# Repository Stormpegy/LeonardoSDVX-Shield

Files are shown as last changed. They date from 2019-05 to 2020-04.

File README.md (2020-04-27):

# LeonardoSDVX-Shield

Open source IO shield for homebuilt SDVX / K-Shoot Mania style controllers.

Uses the kicad libraries by sparkfun 
https://github.com/sparkfun/SparkFun-KiCad-Libraries

Uses arduino-kicad-library by Alarm-Siren
https://github.com/Alarm-Siren/arduino-kicad-library

Originally built to use the cons&stuff leovxhq code but pinout has been modified to make some of the routing neater.

Cons&Stuff SDVX guide
[Cons&Stuff](https://consandstuff.github.io/rhythmcons/sound-voltex/sdvx-normal/)

Original code can be found here
[Cons & Stuff leovx Code](https://github.com/consandstuff/sdvx-diy/tree/master/code%20Leonardo/Arduino%20Leonardo)

LED Pinout code changes between original leovx/leovxhq and what is required for this board.  
To update this code look for line 18 on leovx or line 27 on leovxhq and replace with the new example.

Original
`uint8_t ledPins[] = {6,7,8,9,10,11,12};`

New
`uint8_t ledPins[] = {12,11,10,9,8,7,6};`

I won't tell you how to open and flash this code, just download the arduino IDE and google the rest, It's not too complicated, ask on discord if you need a hand.

## Changelog
REV 2 released

- Replaced JST-XH connector footprints with generic 2.54mm header footprints, original footprints were well out of spec and didn't fit 2.54mm headers/plugs; thank you SirusDoma (C&S discord) for bringing this to my attention.

- System pin rotated to have GND on the same side as all other connections (I have also forgotten why the system pin exists but I'm leaving it there /shrug)

- Removed white border on leonardo shield footprint, library updated and included.

## Pinout

|Button	| Pin # | Button # | LED Pin # |
|---|---|---|---|
|Start	| 13 | Button 1 | 12 |
|BT-A	| A0 | Button 2 | 11 |
|FX-L	| A1 | Button 3 | 10 |
|BT-B	| A2 | Button 4 | 9 |
|BT-C	| A3 | Button 5 | 8 |
|FX-R	| A4 | Button 6 | 7 |
|BT-D	| A5 | Button 7 | 6 |

Encoders | DATA 1 | DATA 2 |
|--------|--------|--------|
|Left knob  (VOL-L) | 0 | 1 |
|Right knob (VOL-R) | 2 | 3 |

## Images

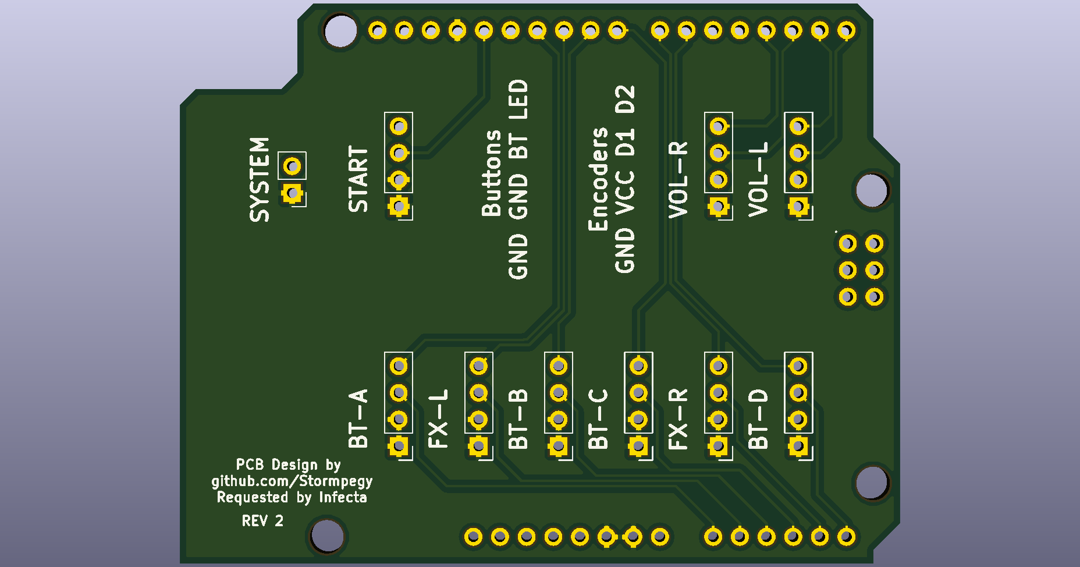
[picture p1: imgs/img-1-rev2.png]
Img Front


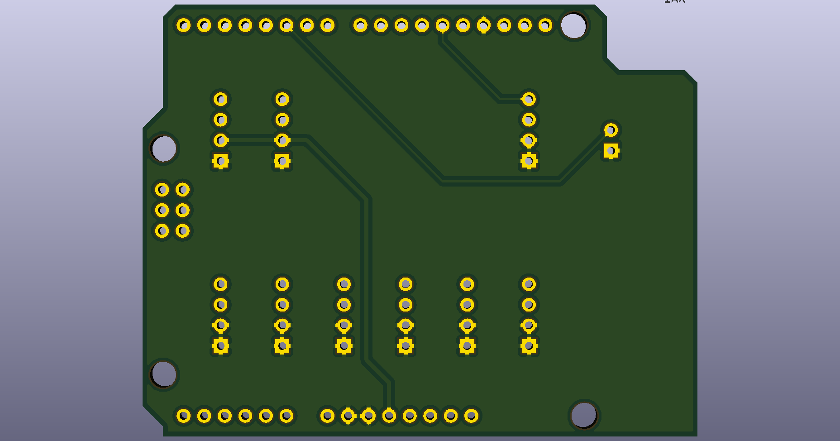
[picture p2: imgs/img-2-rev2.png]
Img Back


## Parts and construction

x32 header pins, standard 2.54mm spacing (Optional +2 if you wish to put headers on the system pins)

Very cheap, Can be found for as cheap as $1USD for 10pcs 40pin online.

x9 JST-XH 4 Pin style straight THT connectors (Ensure you get straight through hole, you will ~~likely~~ definitely struggle if you get right angle or smd)

These XH connectors can be found as sets with cables as well, It's recommend to get 25-35cm wires if you get a set.
JST brand is not important, Just ensure they are XH style spacing (2.5mm/2.54mm)

Crimps, Buttons, Leonardo and all the other parts to build a controller are also required but this just covers the parts for this shield, reference the cons&stuff for a great guide on making your own controller.

## Ordering
These can be ordered very cheaply through a PCB manufacturer such as JLCPCB, they cost $2USD for 5-10qty and shipping is around $5USD to Malaysia and $6USD to Australia.

Simply download LeonardoSDVX-Shield-Gerber.zip and upload it to your preferred PCB manufacturer, I use JLCPCB though there are plenty out there.

I highly recommend leaving the settings on JLCPCB as default unless you know what you're doing.

Layers - 2

Dimensions - 53 x 69 mm, don't change, it automatically enters these.

PCB thickness - 1.6mm

PCB Colour - Feel free to change this one though it will cost more, they use black silkscreen for white pcbs and white silkscreen for everything else.

Surface - HASL (with lead) (Other options are more expensive and not worth it for this simple board)

Copper weight - 1oz

Gold fingers - No

Panel - No

Different design - 1

## To do list
- [x] Make parts list

- [x] Add imgs to readme.md (this doc)

- [x] Add more info on the code change / LED pinout change

- [x] Modify the shield footprint to remove the white outline? unsure how that will go with manufacturing

- [x] Fix the big mistake on rev 1 :)

## Contact and Modifications
Created by https://github.com/Stormpegy
Feel free to contact me in the cons&stuff discord server under the same username for any assistance.

Cons&stuff discord can be found here.  
https://consandstuff.github.io/

Feel free to modify and redistribute this design in any way you please just give credit for original design and keep appropriate links and licenses for the used libraries.

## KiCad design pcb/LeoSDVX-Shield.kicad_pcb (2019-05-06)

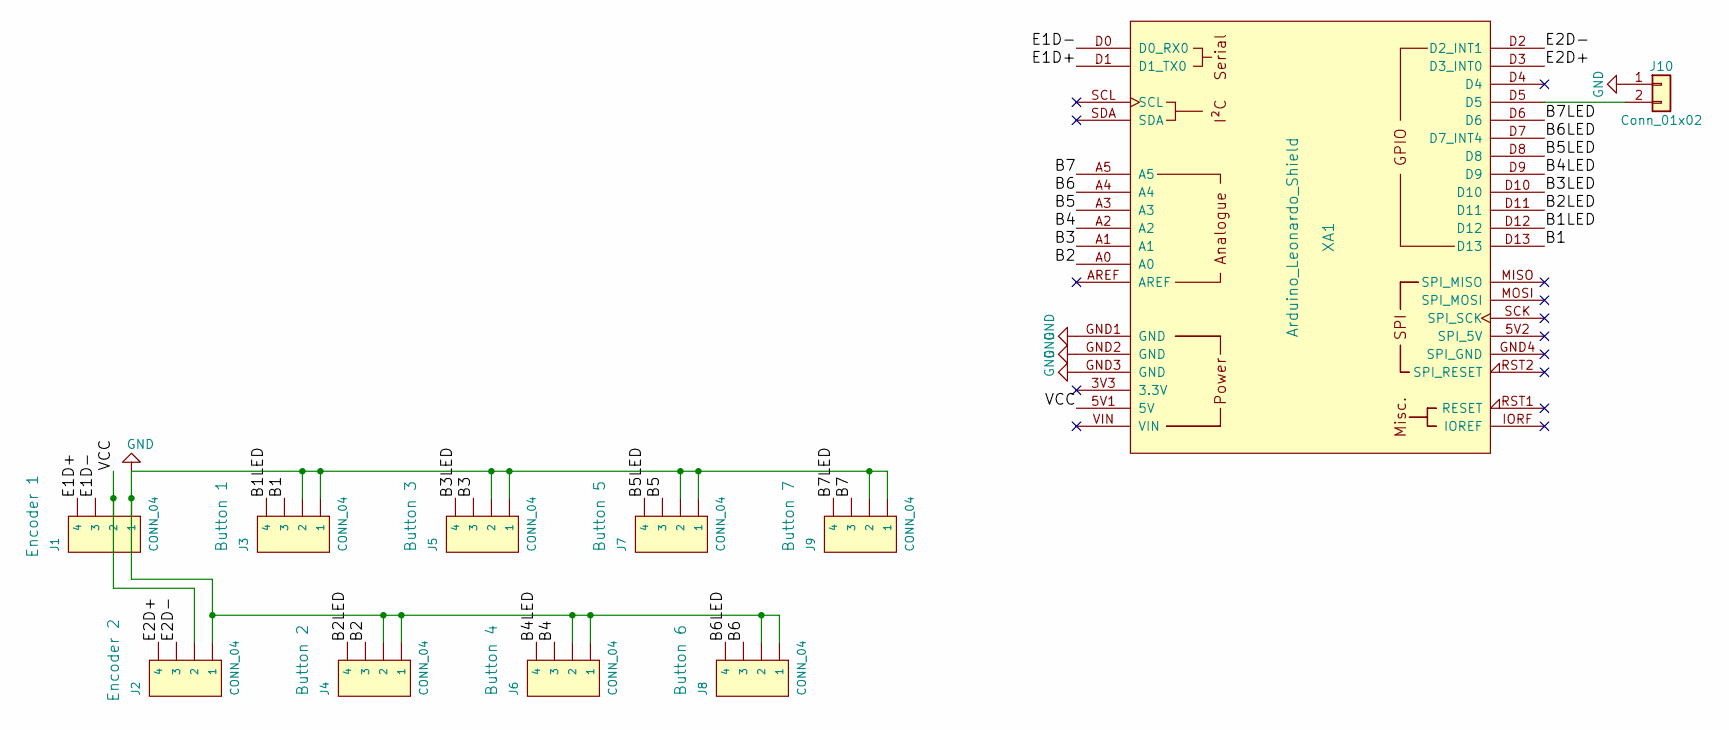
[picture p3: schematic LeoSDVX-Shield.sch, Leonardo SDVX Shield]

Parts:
J1, J2, J3, J4, J5, J6, J7, J8, J9: CONN_04; Pin_Header_Straight_1x04_Pitch2.54mm
J10: Conn_01x02; Pin_Header_Straight_1x02_Pitch2.54mm
XA1: Arduino_Leonardo_Shield; Arduino_Leonardo_Shield_noborder

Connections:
/B1: J3.3, XA1.D13
/B1LED: J3.4, XA1.D12
/B2: J4.3, XA1.A0
/B2LED: J4.4, XA1.D11
/B3: J5.3, XA1.A1
/B3LED: J5.4, XA1.D10
/B4: J6.3, XA1.A2
/B4LED: J6.4, XA1.D9
/B5: J7.3, XA1.A3
/B5LED: J7.4, XA1.D8
/B6: J8.3, XA1.A4
/B6LED: J8.4, XA1.D7 (D7_INT4)
/B7: J9.3, XA1.A5
/B7LED: J9.4, XA1.D6
/E1D+: J1.4, XA1.D1 (D1_TX0)
/E1D-: J1.3, XA1.D0 (D0_RX0)
/E2D+: J2.4, XA1.D3 (D3_INT0)
/E2D-: J2.3, XA1.D2 (D2_INT1)
/VCC: J1.2, J2.2, XA1.5V1 (5V)
GND: J1.1, J2.1, J3.1, J3.2, J4.1, J4.2, J5.1, J5.2, J6.1, J6.2, J7.1, J7.2, J8.1, J8.2, J9.1, J9.2, J10.1, XA1.GND1 (GND), XA1.GND2 (GND), XA1.GND3 (GND)
unnamed: J10.2, XA1.D5

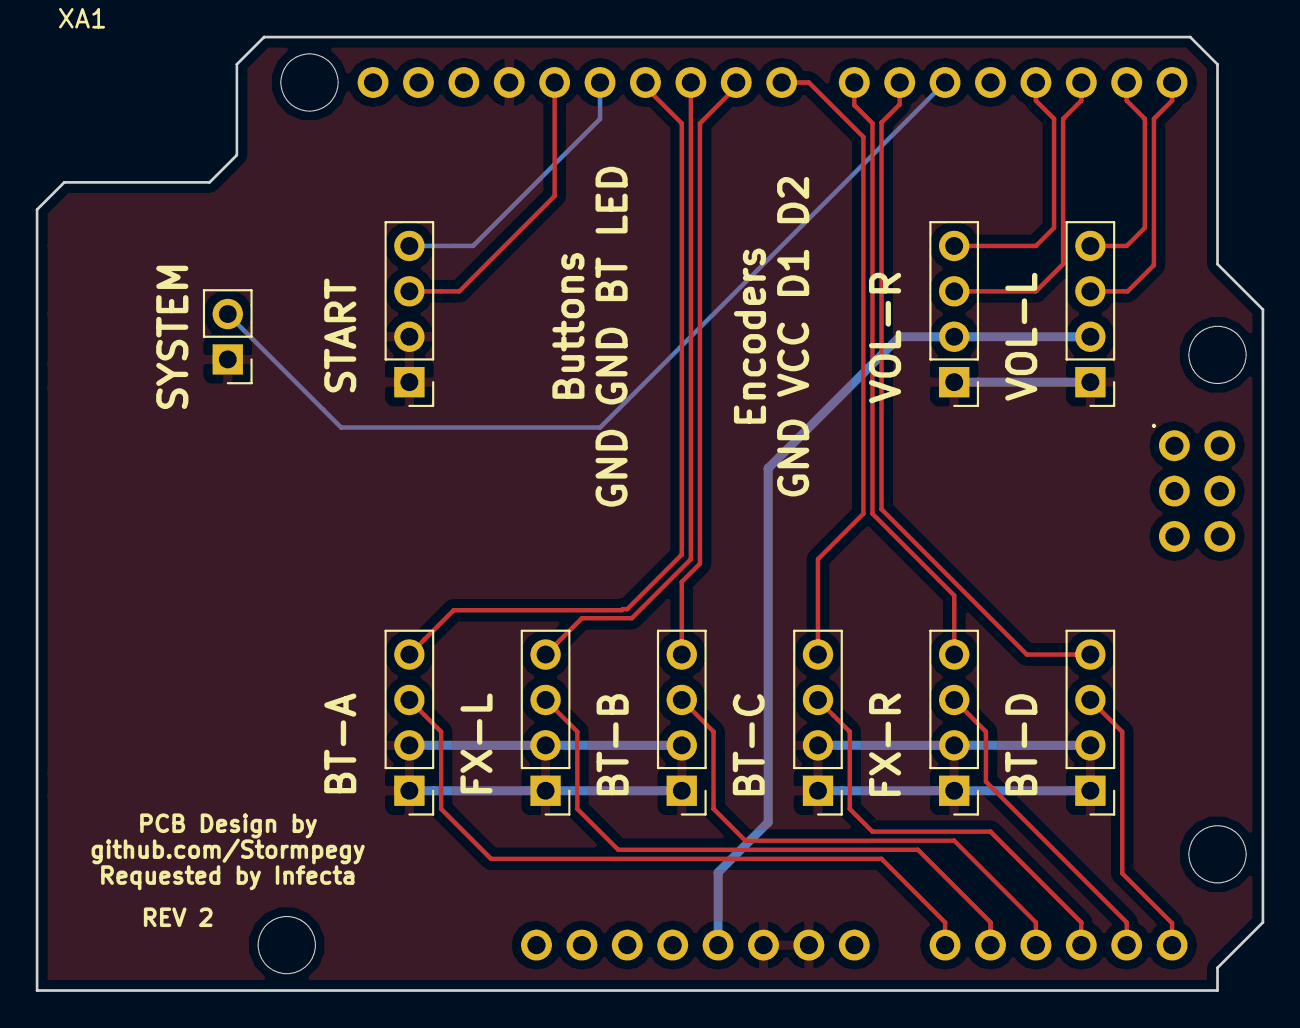
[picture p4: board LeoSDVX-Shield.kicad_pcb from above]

Board: 2 copper layers, 68.6 x 53.3 mm, 11 parts (0 on the bottom side), 21 nets.

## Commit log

2018-08-10 Gerber added, Imgs added
    Created v1 gerber files
    Added images of the pcb
    Updated readme, added to do list
    [LeoSDVX-Shield-B.Cu.gbr, LeoSDVX-Shield-B.Mask.gbr, LeoSDVX-Shield-B.Paste.gbr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]
2018-08-10 Update to various
    Updated readme.md
    -Updated ordering section
    -Added item to to do list
    Updated pcb design
    -Moved 1 trace to match others and updated gnd fill
    Updated gerbers to match the pcb update
    [LeoSDVX-Shield-B.Cu.gbr, LeoSDVX-Shield-B.Mask.gbr, LeoSDVX-Shield-B.Paste.gbr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]
2019-05-06 Revision 2
    REV 2 released
    - Replaced JST-XH connector footprints with generic 2.54mm header footprints, original footprints were well out of spec and didn't fit 2.54mm headers/plugs; thank you SirusDoma (C&S discord) for bringing this to my attention.
    - System pin rotated to have GND on the same side as all other connections (I have also forgotten why the system pin exists but I'm leaving it there /shrug)
    - Removed white border on leonardo shield footprint, library updated and included
    Hopefully the last update this will need
    [LeoSDVX-Shield-B.Cu.gbl, LeoSDVX-Shield-B.Cu.gbr, LeoSDVX-Shield-B.Mask.gbs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]
